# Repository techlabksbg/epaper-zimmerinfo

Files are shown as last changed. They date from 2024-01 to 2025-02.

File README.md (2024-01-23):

 # E-Paper Display mit Schulzimmerbelegungsplan.

## Idee
  * Input ICS + aktuelles Datum
  * Erzeugung einer 800x480 PNG-Datei (vorzugsweise via vektorielles Format).
  * Dithering und Konvertierung in 96kB binäre Daten.
  * Bereitstellen der Daten auf dem Server
  * ESP32 pollt Server via https, holt Daten, stellt diese auf dem Display dar.

ESP32 identifiziert gegenüber dem Server (z.B. via Mac-Adresse).

## Links zu ReadMe 
[Hier](basics/ics/README.md) geht es zum icalender  
[Hier](INSTALL.md) geht es zur benötigten Software

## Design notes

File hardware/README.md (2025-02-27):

# Hardware
  * ESP32-Mikrokontroller mit WaveShare DriverHat: https://www.aliexpress.com/item/1005001881216085.html
  * Displays: https://www.aliexpress.com/item/1005005121813674.html
  * TPS63020 Boost Converter: https://www.aliexpress.com/item/1005006167904909.html
  * DS3231: (And https://microcontrollerslab.com/esp32-ds3231-real-time-clock-rtc-oled/)

## Masse
Display: 
  * Aussen: 111mm x 170mm
  * Rand link, oben, rechts: 4mm, unten 10mm
  * Ribbon unten: 73mm, 22mm 75mm, kann auf 1mm umgebogen werden. Ribbon-Länge 24mm, Kontakt 4mm

# Schemas
## WaveShare ESP32 Driver Board
  * Wiki: https://www.waveshare.com/wiki/E-Paper_ESP32_Driver_Board
  * Allgemein ESP32 Pinout: https://randomnerdtutorials.com/esp32-pinout-reference-gpios/
### Gebrauchte Pins:
  * Driver Board: 13, 14, 15, 25, 26, 27
  * Batterie-Sensor: 34, Power-Switch 32
  * RTC DS3231: I2C-Default Pins: 21 (SDA), 22 (SCL)
### Noch freie Pins:
  * Problemlos: 4, 16 (UART 2 RX), 17 (UART 2 TX), 18, 19 (nicht angeschrieben, zwischen 18 und GND), ~21~, ~22~, 23, ~32~, 33, (Input only: ~34~, 35)
  * With care: 2 (LED, must be floating or low at boot), 12 (boot fails if HIGH)
## TPS63020
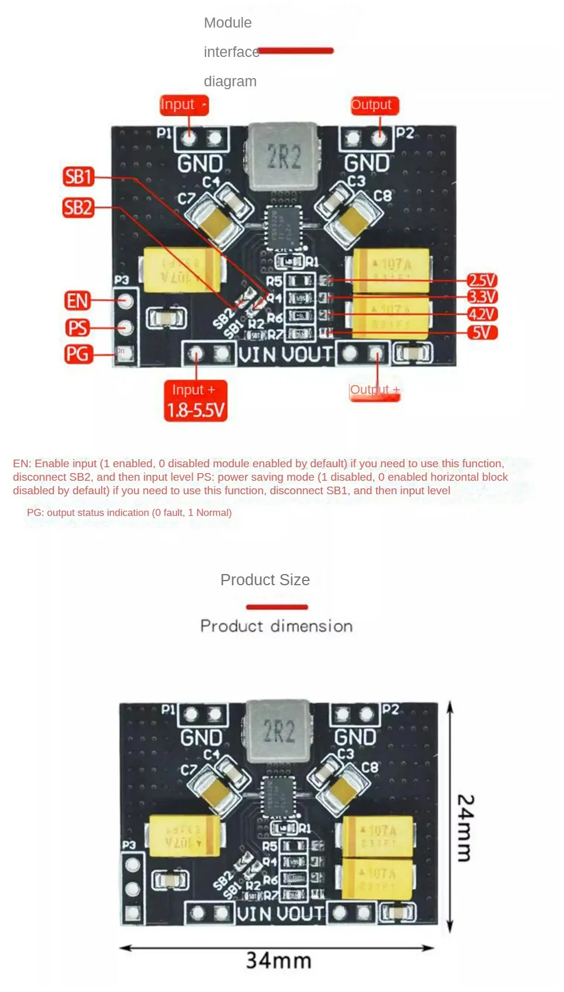
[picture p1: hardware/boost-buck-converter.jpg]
TPS63020 Boost Converter


## Solar?
https://www.instructables.com/The-Reverse-Joule-Thief-Battery-Charger/

## DS3231
  * Library: https://registry.platformio.org/libraries/erriez/ErriezDS3231
  * SDA: 21, SCL: 22

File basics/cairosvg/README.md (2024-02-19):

# Pixel perfect graphics

## Fonts
  * https://graphicdesign.stackexchange.com/questions/11372/what-fonts-are-ideal-for-e-ink-displays
  * https://www.reddit.com/r/typography/comments/gcyxkq/what_fonts_would_you_recommend_for_eink_screens/
    * https://fonts.google.com/specimen/Alegreya
    * https://www.huertatipografica.com/en/fonts/bitter-ht  
    * https://fonts.google.com/specimen/Vollkorn?category=Serif
    * https://fonts.google.com/specimen/Crimson+Pro
    * https://www.onlinewebfonts.com/download/619b4b6d1d4027ed003e71057da6c535

### Konverter
  * https://kapusta.cc/2019/02/10/font2bytes/

## SVG
Wird eine Linie auf Pixelgrenzen gezogen, wird diese auf beide Pixel ausgedehnt (Anti-Aliasing).
Abhilfe schafft man, indem man die Linie in der Mitte der Pixel (halbe Koordinaten) platziert.
Oder den dargestellten Bildausschnitt bei (-0.5, -0.5) starten lässt.

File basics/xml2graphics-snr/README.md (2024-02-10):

# XML to Graphics 
Konvertierung der XML-Daten zu einer png-Grafik, Auflösung 800x480, in schwarz, weiss und rot.

## Brainstorm
  * SVG generieren
  * mit library nach PNG (z.B. mit cairo)

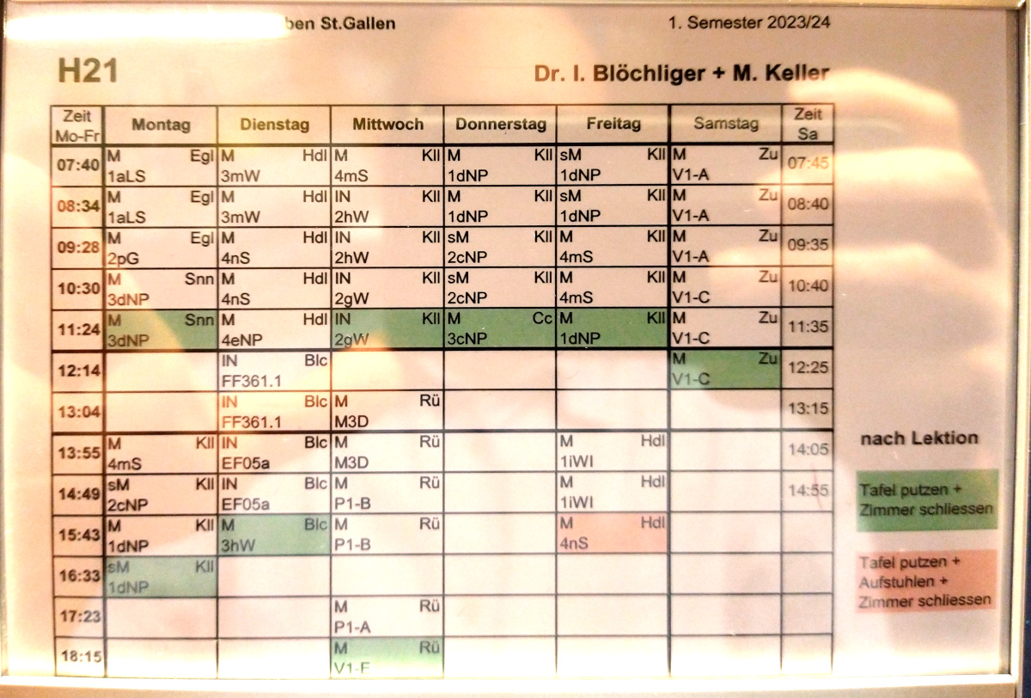
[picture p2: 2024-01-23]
basics/xml2graphics-snr/wooden-paper.jpg

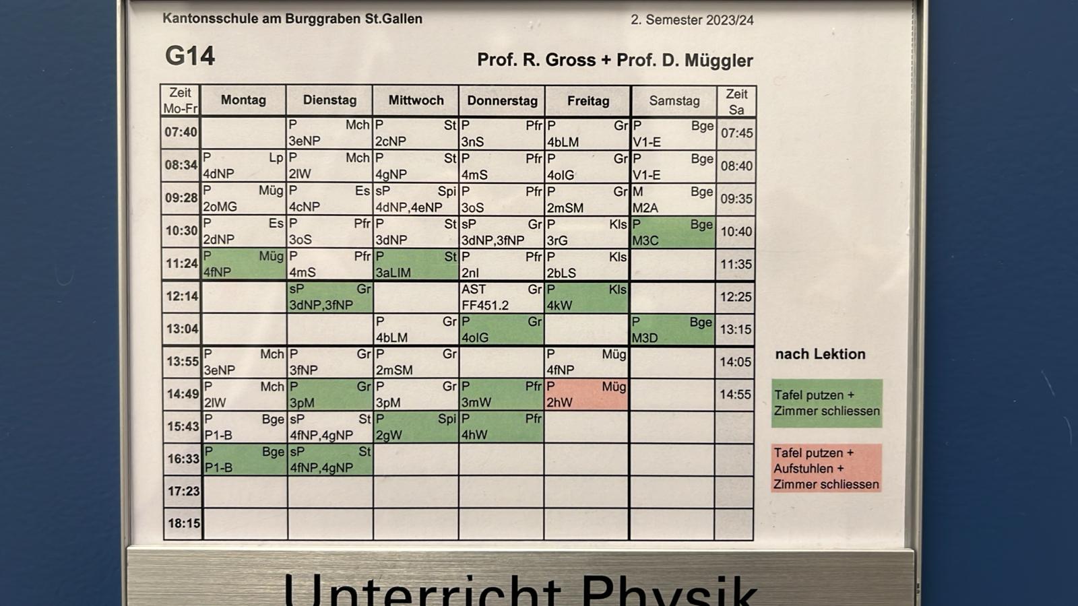
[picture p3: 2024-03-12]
basics/xml2graphics/G14.jpeg

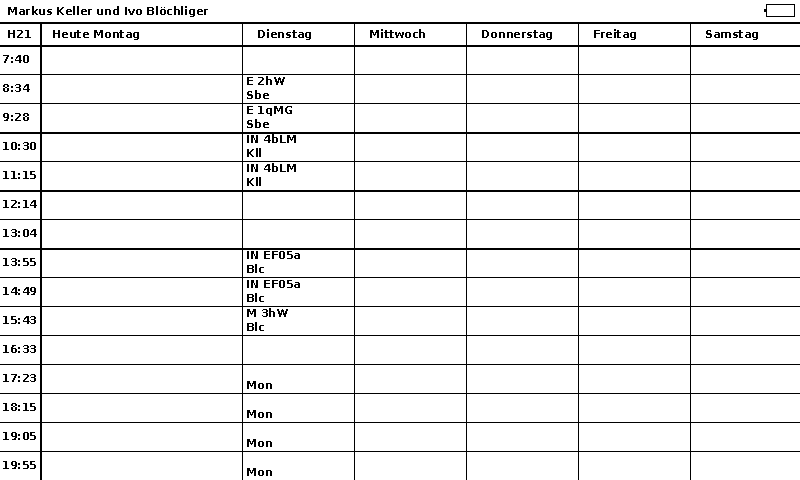
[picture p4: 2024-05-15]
basics/graphlib/bw.png

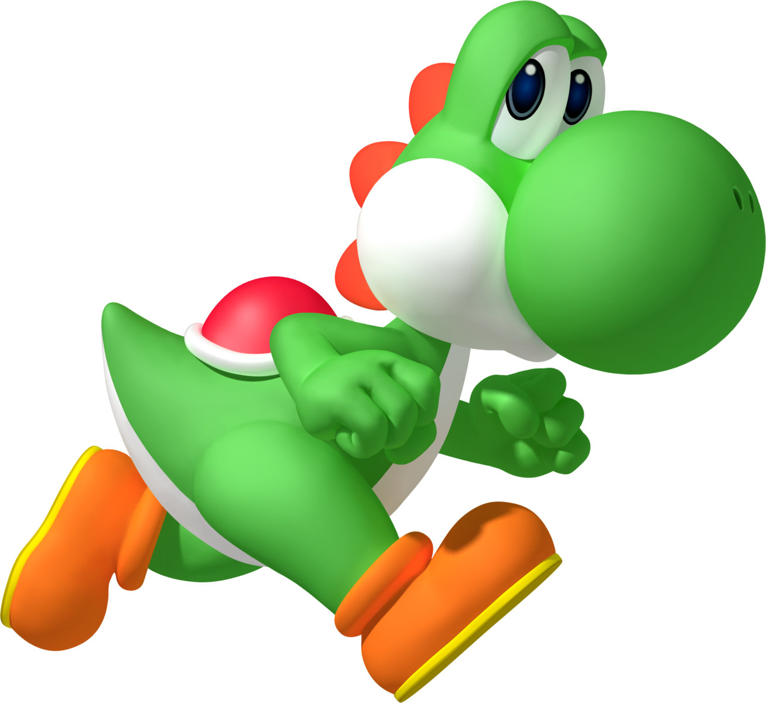
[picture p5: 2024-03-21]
basics/server/static_uploads_pngguru.png

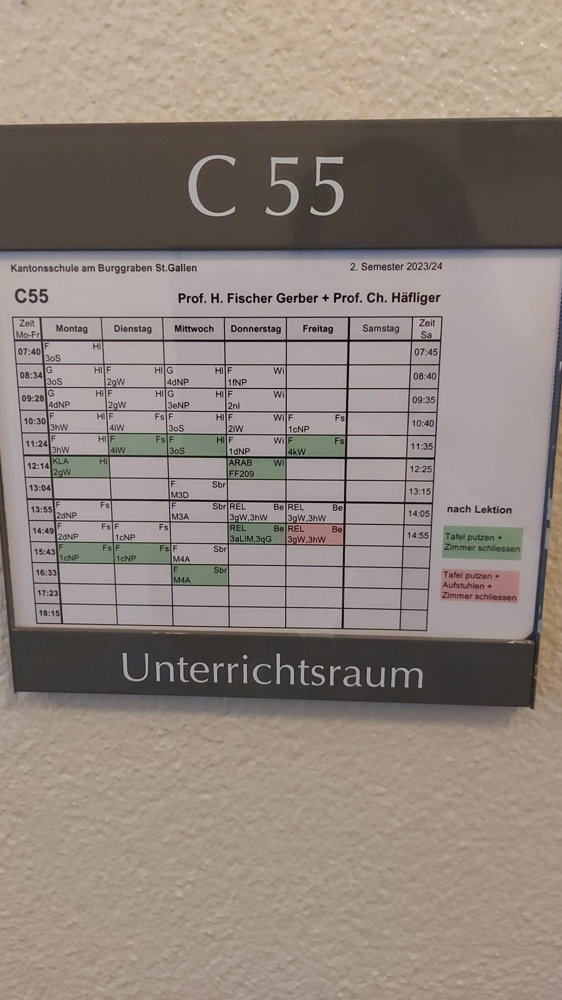
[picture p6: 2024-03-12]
basics/xml2graphics/C55.jpeg

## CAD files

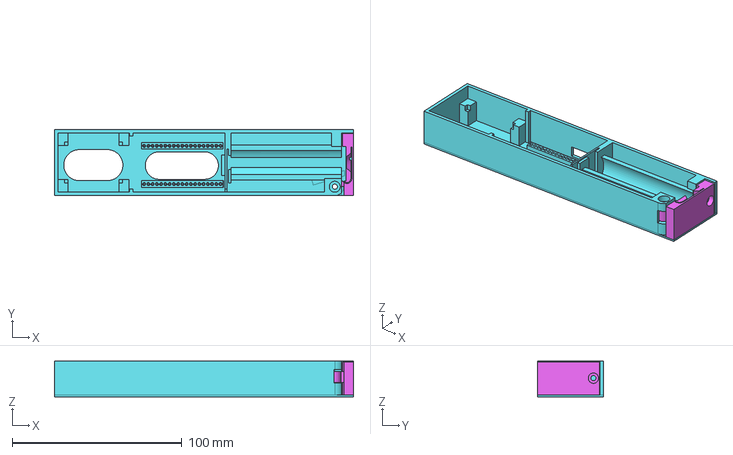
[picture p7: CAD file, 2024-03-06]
hardware/cad/gehaeuse.FCStd
176.0 x 39.0 x 21.0 mm
latch

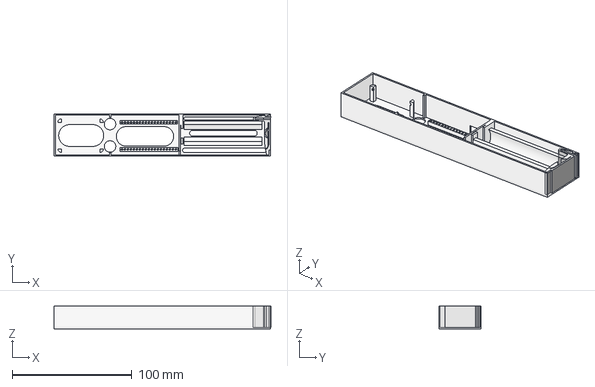
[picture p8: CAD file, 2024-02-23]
hardware/cad/grobskizze.FCStd
181.0 x 35.4 x 19.0 mm
latch

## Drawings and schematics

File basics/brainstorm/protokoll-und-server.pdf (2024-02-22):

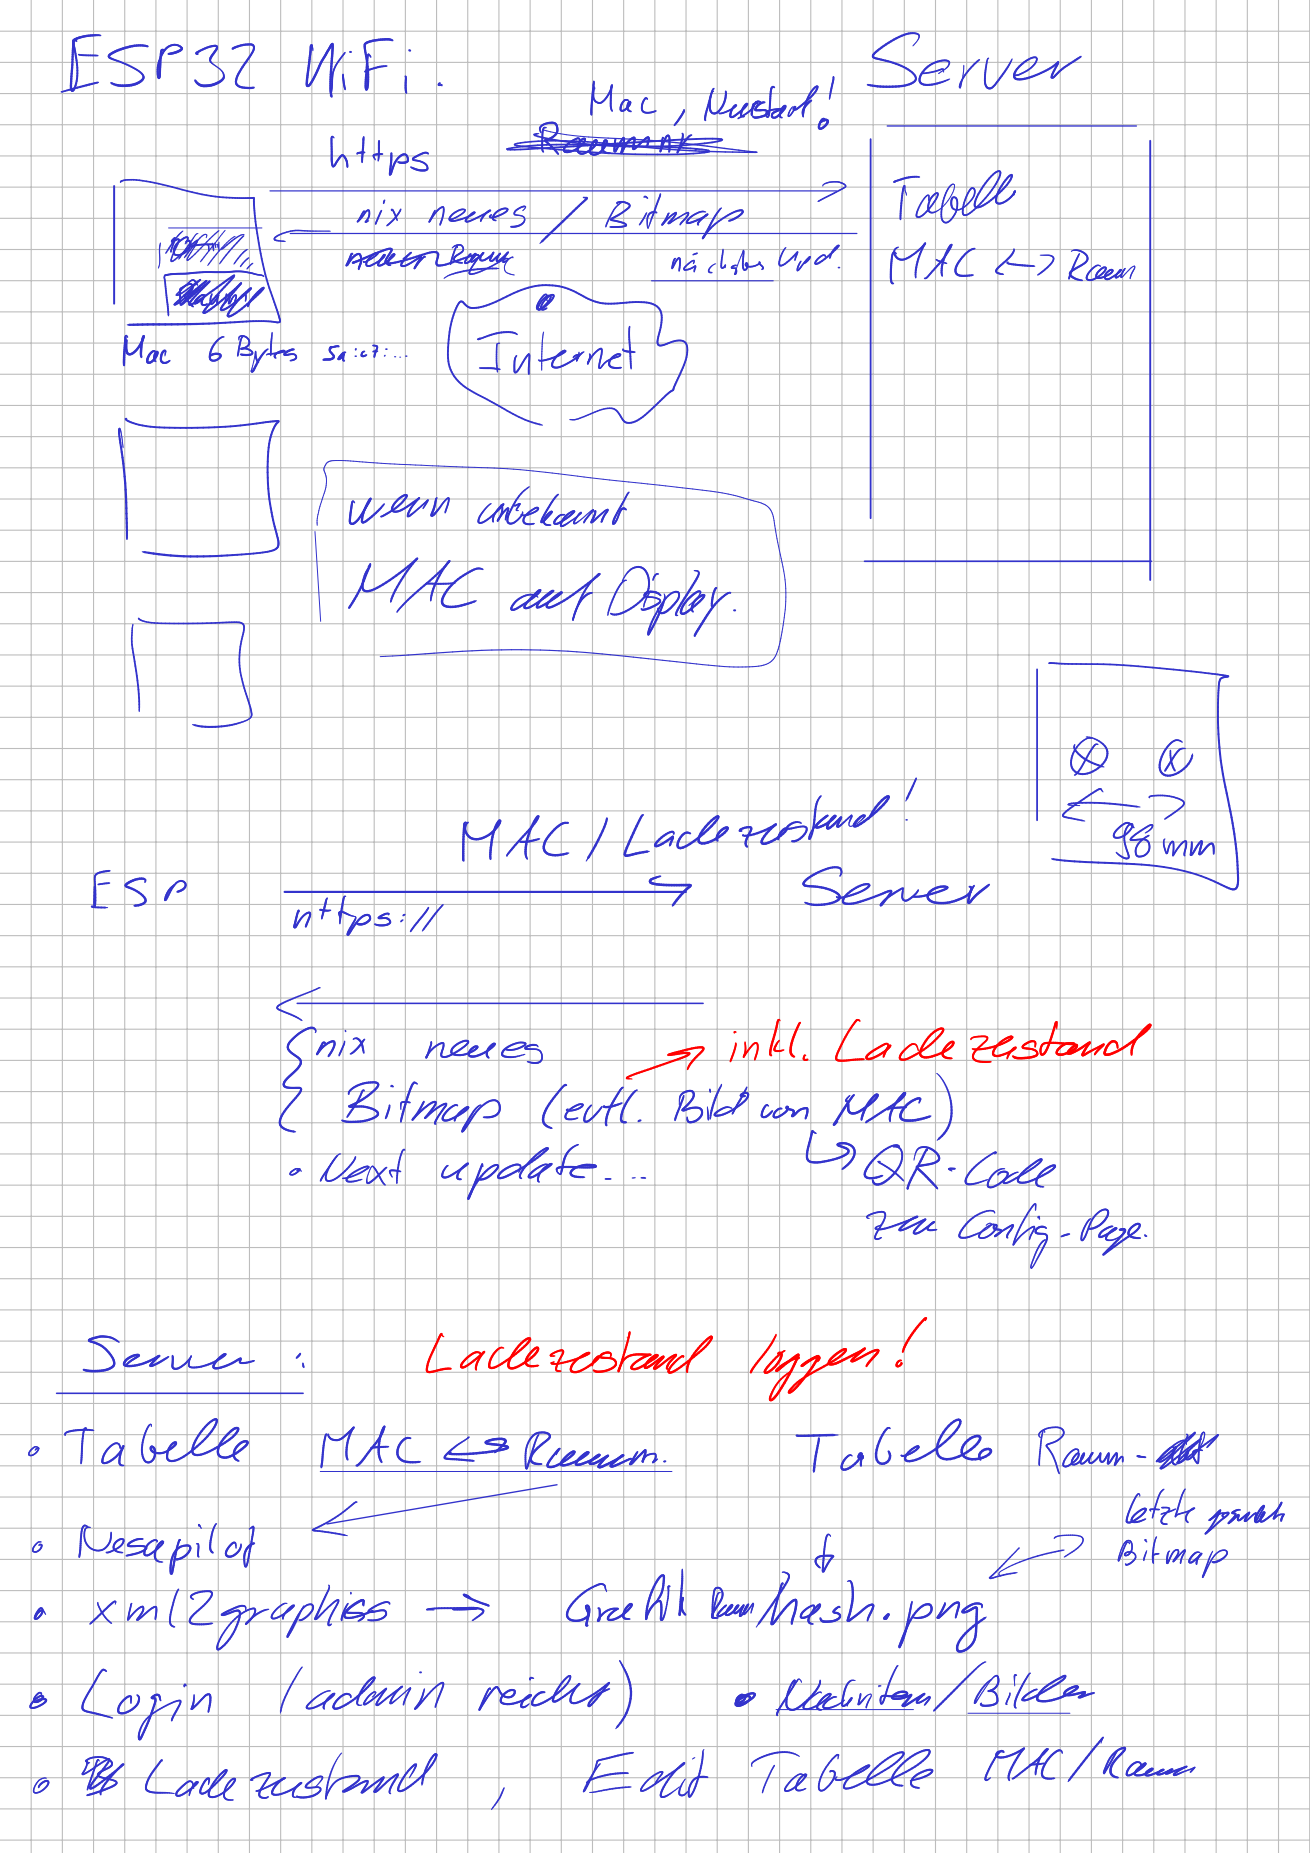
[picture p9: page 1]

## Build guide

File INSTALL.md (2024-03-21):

# Benötige Software für das Projekt
Allgemein:
  * Visual Studio Code (via Windows AppStore)
  * Python3 (via Windows AppStore)
  * git (https://gitforwindows.org/)
    * bash (bereits in git als git-bash enthalten)
    * ssh (nach einem Vierteljahrhundert jetzt auch native in Windows enthalten)

## Python libraries
Siehe [Dependencies](python-dependencies.txt).

Es wird empfohlen ein virtuelles Python environment aufzusetzen. Das Script

[install-deps.bash](install-deps.bash)

erledigt das Aufsetzen des venv (in .venv) und installiert gleich auch alle nötigen packages.

Das Environment muss auf der Kommandozeile mit
```bash
source .venv/bin/activate
```
gestartet werden.

[Zurück](README.md) zum README

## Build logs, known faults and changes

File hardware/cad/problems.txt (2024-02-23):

Kabelschlitz: zu schmal, Position falsch
Länge Box beim Wander zu lang
Wände zu flimsy -> 2mm dicke, mehr vertikal-Verstrebungen
Box zu niedrig (Batterie-Kontakte sind 19mm hoch)
Halter Wandler, Redesign (pressfit vom Deckel)
Batterieverschluss: Gap zu klein (kein Kontakt), Verschluss mit Schraube
Deckel mit Latches.

evtl. PCB für Spannungsteiler. Pins auf ESP prüfen.

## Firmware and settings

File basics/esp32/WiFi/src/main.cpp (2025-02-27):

#include <Arduino.h>
#include <WiFi.h>

/*
The following file contains something like
#define SSID "Lord of the Pings"
#define PASSWD "MyPrecious"
#define SERVERURL "https://example.com"
*/
#include "secrets.h"
#include "DEV_Config.h"
#include "EPD.h"
#include "GUI_Paint.h"
#include <stdlib.h>
#include <string>

#include "soc/soc.h"
#include "soc/rtc_cntl_reg.h"

#include "httpsRequest.h"
#include "httpsota.h"
#include "firmware-version.h"
#include "drawBattery.h"

#define POWER_PIN 32
#define BATPIN 34



RTC_DATA_ATTR int nocon;
RTC_DATA_ATTR char bildhash[20];
// Also see https://randomnerdtutorials.com/esp32-adc-analog-read-arduino-ide/

void goToSleep(long long time);
void errorScreen(String fehler, UBYTE *BlackImage, int ScreenSize);

void flash(int times, int on, int off) {
  for (int i=0; i<times; i++) {
    digitalWrite(BUILTIN_LED, HIGH);
    delay(on);
    digitalWrite(BUILTIN_LED, LOW);
    delay(off);
  }
}

void fadeout() {
  for (int i=0; i<1000; i++) {
    digitalWrite(BUILTIN_LED, HIGH);
    delayMicroseconds(1000-i);
    digitalWrite(BUILTIN_LED, LOW);
    delayMicroseconds(i);
  }
}

void initWiFi() {
  Serial.println(SSID);
  WiFi.mode(WIFI_STA);
  WiFi.begin(SSID, PASSWD);
  Serial.print("Connecting to WiFi ..");
  int seconds = 20;
  while (WiFi.status() !=WL_CONNECTED && seconds>0) {
    Serial.print(".");
    delay(1000);
    flash(1, 10, 0);
    seconds--;
  }
}

double voltage=0.0;
int adValue = 0;
//from basics/esp32/batterie_messung
float batterie_messung() {
  adValue = 0;
  for (int i=0; i<100; i++) {
    adValue += analogRead(BATPIN);
    delay(10);
  }
  // 227056 sollte 4.055 V sein
  // 188410 sollte 3.405 V sein
  voltage = (float)(adValue-188410)/(227056-188410)*(4.055-3.405)+3.405;
  return voltage;
}

void antwort(String response, UBYTE *BlackImage, int ImageSize){
  int pos = 0;
  Serial.println(response);
  while (pos<response.length()) {
    int zeilenende = response.indexOf('\n', pos);
    if (zeilenende<0) {
      zeilenende = response.length();
    }
    int keyende = response.indexOf(' ', pos);
    if (keyende<0) {
      errorScreen(String("Missing space in line"), BlackImage, ImageSize);
    }
    String key = response.substring(pos, keyende);
    String value = response.substring(keyende+1, zeilenende);
    Serial.println(value);
    Serial.printf("key = %s, value=%s pos=%d, keyende=%d, zeilenende=%d\n", key.c_str(), value.c_str(), pos, keyende, zeilenende);
    pos = zeilenende+1;
    if (key == "sleep"){
      nocon=0;
      goToSleep(value.toInt());
    }
    if (key == "bild"){
      if (!value.startsWith("https://")) {
        value = String(SERVERURL)+value;
      }
      int len = request(value,(char*)BlackImage, ImageSize*2);
      if (len!=ImageSize*2) {
        errorScreen(String("https-Request has only size ")+String(len), BlackImage, ImageSize);
      } else {
        WiFi.disconnect(true);
        WiFi.mode(WIFI_OFF);
        //hier kann WiFI abgeschaltet werden
        Serial.println("Displaying graphics");
        DEV_Module_Init();
        EPD_7IN5B_V2_Init();
        drawBattery(voltage, 740,3, BlackImage, BlackImage+ImageSize);
        //EPD_7IN5B_V2_Clear();
        EPD_7IN5B_V2_Display(BlackImage, BlackImage+ImageSize);
        EPD_7IN5B_V2_Sleep();
      }
    }
    if (key=="hash"){
      if (value.length()<20) {
        strncpy(bildhash, value.c_str(), 19);
        Serial.print("Set bildhash to ");
        Serial.println(value);
      }
    }
    if (key == "update") {
      httpsOTA(value);
      errorScreen(String("OTA via https failed "), BlackImage, ImageSize);
    }
  }
}

void goToSleep(long long time){
  Serial.printf("Going deepsleep for %d seconds", time);
  fadeout();
  digitalWrite(POWER_PIN, LOW);
  delay(500);
  esp_sleep_enable_timer_wakeup(time*1000000ULL);
  esp_deep_sleep_start();
}

void errorScreen(String fehler, UBYTE *BlackImage, int ImageSize) {
  nocon = nocon+1;
  String MAC = "MAC: " + String(WiFi.macAddress());
  String battery = "Batteriespannung: " + String(voltage) + "V adValue=" + String(adValue);
  // Set images to white here!
  printf("NewImage:BlackImage and RYImage\r\n");
  Paint_NewImage(BlackImage, EPD_7IN5B_V2_WIDTH, EPD_7IN5B_V2_HEIGHT , 0, WHITE);
  Paint_NewImage(BlackImage+ImageSize, EPD_7IN5B_V2_WIDTH, EPD_7IN5B_V2_HEIGHT , 0, WHITE);
  Paint_SelectImage(BlackImage+ImageSize);
  Paint_Clear(WHITE);
  Paint_SelectImage(BlackImage);
  Paint_Clear(WHITE);
  
  Paint_DrawString_EN(100,100, fehler.c_str(), &Font16, WHITE, BLACK);
  Paint_DrawString_EN(100,150, "SSID " SSID, &Font16, WHITE, BLACK);
  Paint_DrawString_EN(100,180, MAC.c_str(), &Font16, WHITE, BLACK);
  Paint_DrawString_EN(100,210, battery.c_str(), &Font16, WHITE, BLACK);

  drawBattery(voltage, 740,10, BlackImage, BlackImage+ImageSize);

  WiFi.disconnect(true);
  WiFi.mode(WIFI_OFF);
  printf("EPD_Display\r\n");
  DEV_Module_Init();
  EPD_7IN5B_V2_Init();
  //EPD_7IN5B_V2_Clear();
  EPD_7IN5B_V2_Display(BlackImage, BlackImage+ImageSize);
  EPD_7IN5B_V2_Sleep();
  delay(1000);
  goToSleep(60*(1<<nocon));
}

void setup(){
  // Disable Brownout Detection 
  WRITE_PERI_REG(RTC_CNTL_BROWN_OUT_REG, 0);
  pinMode(POWER_PIN, OUTPUT);
  digitalWrite(POWER_PIN, HIGH);  // Switch power on

  Serial.begin(115200);
  Serial.println("MAC-Address:");
  Serial.println(WiFi.macAddress());
  batterie_messung();
  //voltage = 3.7;
  Serial.printf("Batterie-Spannung: %.2fV -> %d%% (from adValue=%d)\n",voltage,percentage(voltage), adValue);
  pinMode(BUILTIN_LED, OUTPUT);
  flash(2, 20, 300);
  if (esp_sleep_get_wakeup_cause()!=ESP_SLEEP_WAKEUP_TIMER){
    bildhash[0]=0;
    nocon=0;
  }

  printf("e-Paper Init and Clear...\r\n");
  //EPD_7IN5B_V2_Clear();
  DEV_Delay_ms(500);
  UBYTE *BlackImage, *RYImage;
  UWORD Imagesize = ((EPD_7IN5B_V2_WIDTH % 8 == 0) ? (EPD_7IN5B_V2_WIDTH / 8 ) : (EPD_7IN5B_V2_WIDTH / 8 + 1)) * EPD_7IN5B_V2_HEIGHT;
  if ((BlackImage = (UBYTE *)malloc(Imagesize*2)) == NULL) {
    printf("Failed to apply for black memory...\r\n");
    while(1);
    //LED blinken lassen
  }
  RYImage=BlackImage+Imagesize;
  Paint_NewImage(BlackImage, EPD_7IN5B_V2_WIDTH, EPD_7IN5B_V2_HEIGHT , 0, WHITE);
  Paint_SelectImage(BlackImage);
  Paint_Clear(WHITE);
  Paint_NewImage(RYImage, EPD_7IN5B_V2_WIDTH, EPD_7IN5B_V2_HEIGHT , 0, WHITE);
  Paint_SelectImage(RYImage);
  Paint_Clear(WHITE);


  

  Serial.println("WiFi-Init...");
  initWiFi();
  if (WiFi.status() !=WL_CONNECTED) {
    Serial.println("Keine WiFi-Verbindung...");
    errorScreen("Keine WiFi-Verbindung", BlackImage, Imagesize);

  }
  else{
    String mac = WiFi.macAddress();
    Serial.println("MAC-Address");
    Serial.println(mac);
    flash(5, 10, 100);
    int len = request(String(SERVERURL)+"anzeige?mac="+mac+"&volt="+String(voltage)+"&hash="+bildhash+"&firmware="+FIRMWARE+"&nocon="+String(nocon), (char *)BlackImage, Imagesize*2);
    BlackImage[len]=0;
    String response = String((char*)BlackImage);
    flash(5,10,100);
    antwort(response, BlackImage, Imagesize);
  }
}

void loop(){}

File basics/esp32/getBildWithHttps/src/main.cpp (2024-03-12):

#include <Arduino.h>
#include <WiFi.h>
#include "DEV_Config.h"
#include "EPD.h"
#include "GUI_Paint.h"
#include <stdlib.h>

#include "secrets.h"
#include "httpsRequest.h"

int nocon=0;
// Also see https://randomnerdtutorials.com/esp32-adc-analog-read-arduino-ide/
#define BATPIN 34

void initWiFi() {
  WiFi.mode(WIFI_STA);
  WiFi.begin(SSID, PASSWD);
  Serial.print("Connecting to WiFi ..");
  int seconds = 20;
  while (WiFi.status() !=WL_CONNECTED && seconds>0) {
    Serial.print(".");
    delay(1000);
    seconds--;
  }
  Serial.println(WiFi.localIP());
}


void setup(){
  DEV_Module_Init();
  EPD_7IN5B_V2_Init();

  Serial.begin(115200);
  UBYTE *BlackImage, *RYImage;
  UWORD Imagesize = ((EPD_7IN5B_V2_WIDTH % 8 == 0) ? (EPD_7IN5B_V2_WIDTH / 8 ) : (EPD_7IN5B_V2_WIDTH / 8 + 1)) * EPD_7IN5B_V2_HEIGHT;
  if ((BlackImage = (UBYTE *)malloc(Imagesize*2)) == NULL) {
    printf("Failed to apply for black and red memory...\r\n");
    while(1);
  }
  RYImage = BlackImage + Imagesize;

  printf("NewImage:BlackImage and RYImage\r\n");
  Paint_NewImage(BlackImage, EPD_7IN5B_V2_WIDTH, EPD_7IN5B_V2_HEIGHT , 0, WHITE);
  Paint_NewImage(RYImage, EPD_7IN5B_V2_WIDTH, EPD_7IN5B_V2_HEIGHT , 0, WHITE);

  initWiFi();
  if (WiFi.status() !=WL_CONNECTED) {
    Serial.println("Not connected!");
    nocon = nocon+1;
    Paint_SelectImage(BlackImage);
    Paint_DrawString_EN(10, 20, SSID, &Font16, WHITE, BLACK);
    Paint_DrawString_EN(10, 40, WiFi.macAddress().c_str(), &Font16, WHITE, BLACK);
  }
  httpsRequest("https://ofi.tech-lab.ch/ef05a/data.bin", (char *)BlackImage, Imagesize*2);
  Serial.println("Displaying graphics");
  EPD_7IN5B_V2_Display(BlackImage, RYImage);
  DEV_Delay_ms(2000);
}

void loop(){}

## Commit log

2024-01-17 basic esp32 codes for display interaction
2024-01-23 Verlinkungen der ReadMe
2024-02-06 sample output
2024-02-08 Kann jtzt ical einlesen und printen
2024-02-10 1st experiments with esp32-c3 super mini
2024-02-23 erste versuche in cad
    [grobskizze.FCStd]
2024-02-27 dithering and transfer to esp32
2024-03-06 cad v0.1
    [gehaeuse.FCStd]
2024-03-07 insert draw lessons
2024-03-11 batterie-messung mit esp32
2024-03-11 ESP32 WIFI
2024-03-12 battery logging
2024-03-12 display battery
2024-03-12 more info when connection fails
    [main.cpp]
2024-03-12 spelling mistakes and other stuff
    [httpsRequest.cpp, main.cpp]
2024-03-12 Kann nun Texte anhand der angegebenen Zeit positionieren (funkt. nur wenn Anfangszeit = Lektionsbeginn)
2024-03-12 combine bw und rw
2024-03-12 battery plotting
2024-03-12 displaying voltage plot under more battery info
2024-03-12 more error screens, better timeouts
    [httpsRequest.cpp, main.cpp]
2024-03-13 led feedback
2024-03-13 der fix für den chaosfix
2024-03-13 Fix für den Scheiss, der duch die packeges und die imports existierte
2024-03-13 Battery indicator added (rip rounded corners)
2024-03-13 better leds while ota
2024-03-13 code with current time and id
2024-03-14 prevent endless loop on unexpected server response
    [main.cpp]
2024-03-14 volt to percentage conversion
2024-03-14 displaying batteryplot when no xml yet
2024-03-14 added current time on image
2024-03-14 displaying battery as percentage
2024-05-17 more debug, fixed error screen
    [main.cpp]
2024-05-21 hardware switch must be on "A"!
2024-05-24 drawing battery symbol on ESP32
2024-05-24 battery drawing on ESP32
2024-06-08 power switch circuit
